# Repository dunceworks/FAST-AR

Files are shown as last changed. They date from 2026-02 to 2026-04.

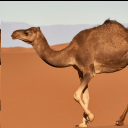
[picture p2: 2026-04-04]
py/test_img_gen/output_img/downscaler_param_128square.png

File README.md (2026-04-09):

# FAST-AR: Framework for Accelerated Spatial awareness in Augmented Reality

Designed to provide accelerated gesture recognition through hardware acceleration of image preprocessing combined with the Xilinx DPU to enable high speed recognition.
Additionally, a Rubik Pi provides video passthrough and "pseudo-stereo" display for the user, allowing for easier integration of the AUP-ZU3 provided gesture data compared to a PL only approach

Note that some work is not present in this repository to prevent bloat. For example PCAM5 video and DPU are in separate repositories or only pieces of them are stored here respectively.
The PCAM repository is separate from this one and can be found at https://github.com/Henrywwg/pcam5.

Uses RGB888 color version

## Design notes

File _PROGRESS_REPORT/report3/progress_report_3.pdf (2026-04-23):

ECE554 | 1
Progress Report
2026-04-23

Members
Henry Wysong
Harshul Jalan
Ananya Virmani
Andrew Cadiena

Current Progress
So far, we have many of the main parts of our MVP at least partially tested. The PS/Rubik Pi based video passthrough is functional. Additionally, the gesture recognition model is almost finalized, undergoing additional minor training to improve confidence. The PL side video input is also working with frames being able to be pushed into main memory. The PS side now also successfully can run our proprietary model. Additionally the frame preprocessing modules are working. A debug video output now also works over mDP. The gesture recognition model also now works on the AUP-ZU3 (at 3.33 spf).

To Do
The main tasks to still complete are with integration and ensuring communication from the AUP-ZU3 to the Rubik Pi.
The IR sensor must still be finalized in its hardware implementation although in testbenching it is working.

What’s been Tested
All of our IP/hardware modules are now successfully testbenched. Below are the modules that are testbenched but are not integrated into the main block diagram yet due to ongoing HW debugging or other integration delays.

Testbenched
The IR sensor interfacing hardware has been testbenched. Additionally all of the secondary/(some) reach modules (such as extra filters) have also been testbenched and are ready to be integrated into the hardware time permitting. Otherwise all other modules have been fully testbenched in modelsim/vivado and are in or past the hardware testing stage.

HW Tested
Below is a list of the IP and hardware components that have been tested and shown working. Proof of this can be found in previous presentations, on github or upon request.
- VDMA
- PCAM/Video input
- Downscaler
- Grayscale

Individual Contributions
Henry
I have worked on the PL video input for gesture recognition along with the downscaler, grayscale and VDMA. Additionally I also was responsible for getting the DPU block diagram working from the HW side. For the downscaler and grayscale, I made an AXI4-Stream interfaces and testbenched the modules. After testbenching, IP was packaged and the block diagram was made. Our final design is the one BD which has the video processing pipeline, which is my main contribution. Co-opted feeding live data from VDMA into the model. I have contributed to getting the model running (from the hardware perspective - not the software) by working on moving data from the PL side into PS. I also have a working demo display that shows the area that is being downscaled to guide users’ gesture/hand positioning.

Andrew
I have helped with VDMA and started the display port to output as one of our backup modules.
Currently I am working on integrating the IR sensor onto the board. The sensor outputs high if it detects an object within a set distance and I plan to then output audio in order to alert the user. The core verilog pipeline is completed, however configuring the AUP’s audio codec is proving a great challenge and I may pivot to another alternative. The current proposed backup is shifting to a PWM module and outputting through one of the boards GPIO pins. With a buzzer or a custom earbud wiring.

Ananya

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
3 I have m

ainly

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
ritin

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
nitio

n

m

o

d

el a

n

d

t

e

s

t

e

d it. Fin

al w

o

r

kin

g

s

o

n it are still in progress just to make sure that it works with the highest possible confidence level and fast. Alongside, I have been working on helping set up the DPU and getting the gesture recognition model to work on it. The DPU seems to be working independently but we are still running into software issues of loading the model on it. Lastly, I have been helping with some stuff on communication with the RubikPi and some integrations. Ananya also got MediaPipe installed and the gesture recognition model running on the AUP. Also co-opted working on feeding live data from VDMA into the model. Harshul I have worked on the PS/Rubik Pi based video passthrough, which is now functional and enables streaming frames into the AUP-ZU3 for further processing. Additionally, I have contributed to overall system integration, ensuring that different components in the pipeline (video capture, preprocessing, and inference) are aligned and can work together. I have also been involved in planning and structuring the communication between the AUP-ZU3 and Rubik Pi. This includes defining how gesture recognition outputs will be sent back for further processing and user interaction. This communication layer is currently still to be implemented as part of the remaining integration work.Additionally, I have the rover (for the headset to interact with and drive the rover using the hand gestures) system set up and ready to receive commands, and I will be working on establishing communication between the two Rubik Pis (on the rover and the VR headset) to enable end-to-end control.

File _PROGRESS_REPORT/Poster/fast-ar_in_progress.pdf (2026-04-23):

## Henry Wysong-Grass Ananya Virmani

## Harshul Jalan Andrew Cadiena

# ECE554 FAST-AR

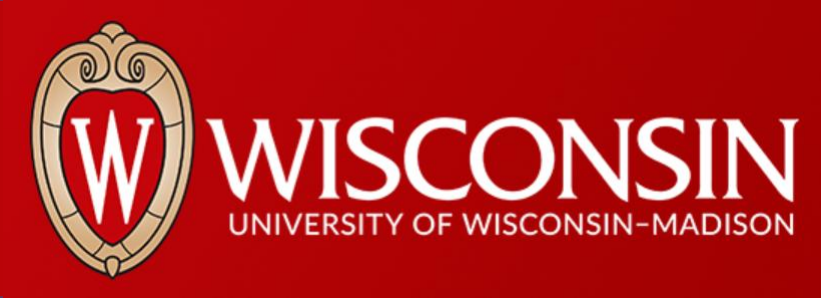
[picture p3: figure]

Overview | Software Pipeline (PS)

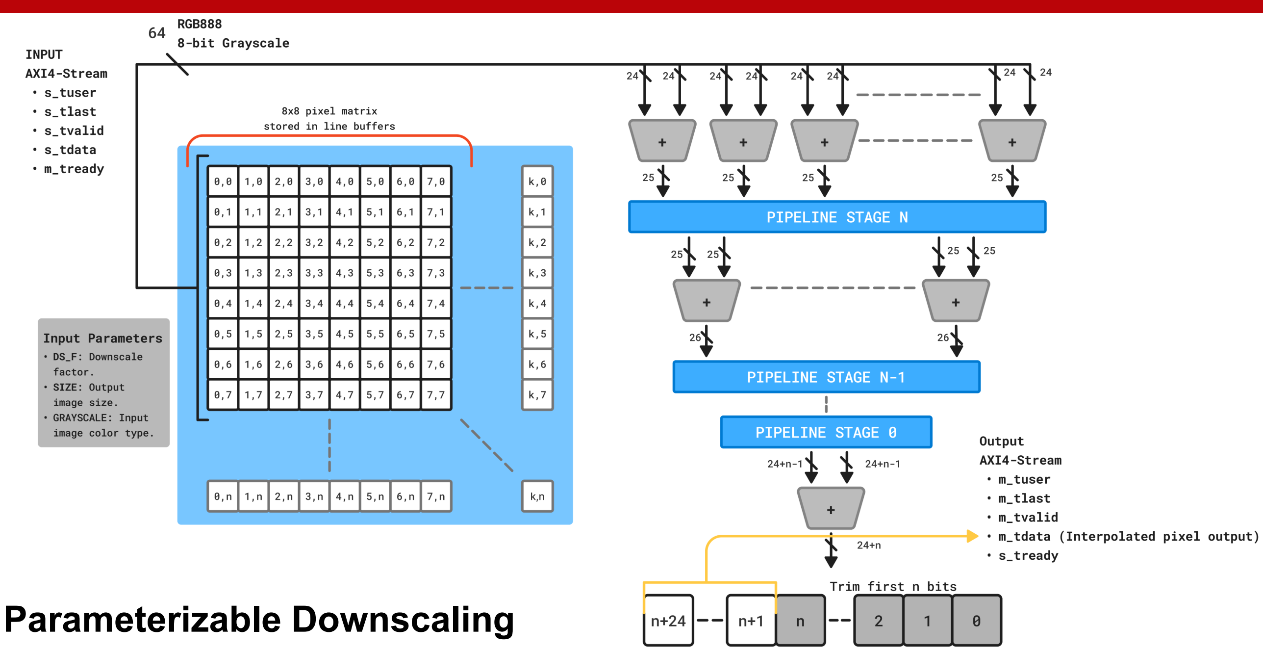
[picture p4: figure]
Parameterizable Downscaling

# Hardware Pipeline (PL)

# Gesture Acceleration Hardware

# Future Work

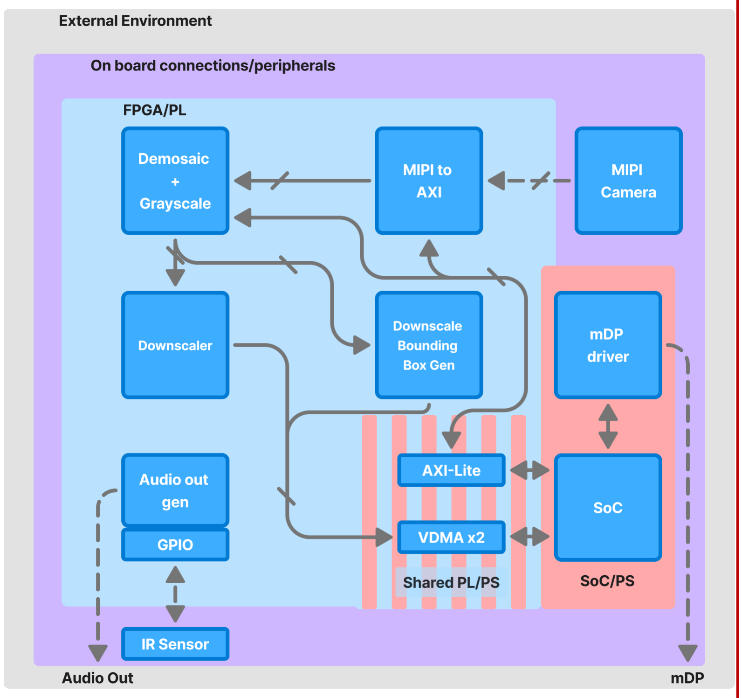
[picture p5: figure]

# Challenges

# Spring 2026

PYNQ Ecosystem
- MediaPipe for the model required internet, but the AUP lacks WiFi or ethernet.
- Long flash times and opacity of the FPGA lead to long software deployments.
- PYNQ’s Jupyter notebooks often disconnect mid program.
Custom IP
- Properly complying with the AXI4-Stream protocol is difficult!
- Cameras are prone to dropping pixels meaning all pipeline hardware must be robust and able to recover based on AXI4-Stream handshake signals. IP Configuration and Documentation
- Vivado/Xilinx IP configuration requires large time sink to both configure properly in hardware and then configure properly over an AXI-lite bus.
Hardware Failures and the AUP-ZU3…
- AUP-ZU3 boards have poor ESD protection and often fail short.
- PCAM5 modules are also sensitive and prone to ESD events.

Deep Processing Unit (DPU) accelerated Gesture Recognition
- DPU is a proprietary RISC core(s) on FPGA fabric that runs the recognition model.
- Zero software overhead but increases HW complexity and configuration complexity. High resolution (4K) global shutter camera
- Global shutter removes motion blur which gives higher quality images to the model.
- Higher resolution gives more data, allowing for better downscaled images. Hardware stereoscopic video pipeline (HW SBS)
- A HW video pipeline reduces software overhead immensely and reduces camera to display latency by an order of magnitude. Below are SWAGs of latency of each.
- HW SWAG → ~3000 cycles @ 200MHz ≈ 15 μS (as low as 100 nS for raw feed)
- SW SWAG → 2 DRAM R/W + SW processing ≈ 25 mS (conservative)
- Streams a 1080p frame and does NxN interpolation taking about 76.8 μS* per frame.
- Uses an auto-pipelining** adder tree to increase odds of meeting timing without designer intervention. No DSP slices are used due to tree design and bit manipulation!
- Operates on both RGB888 data or grayscale data depending on model type. Grayscale operation gives a 2/3 reduction in FPGA resources utilized.
Grayscale
- A module that converts a full color RGB image to a single, averaged channel (8 bit).
- Very useful for resource or compute constrained systems due to 2/3 reduction in data.

* 76.8 μS is the time to downscale one 1080p frame to 224x224 before it is sent to VDMA/Mapped Main Memory assuming operation at 200MHz with no stalls and does not account for blanking time of the frame.
** Automatic pipelining done at instantiation or synthesis.

Video in and Demosaic
- Camera data over 2-lane
CSI as RAW10.
- RAW10 data truncated to
RAW8 and demosaiced.
- Data streams out as
RGB888 over AXI4-Stream.

Primary Pipeline
- RGB data is downscaled
from 1080p to 224x224.
- Downscaled frame is pushed to Video Direct Memory
Access (VDMA).

Secondary/Demo Pipeline
- Split stream is grayscaled.
- A bounding box is drawn
over the downscaling region.
- Bound image sent to VDMA.

### FPGA Accelerated Spatial Tracking in Augmented Reality (FAST-AR)

Objective: Accelerate a gesture recognition model to decrease latency for augmented reality controls.

Architecture: Heterogenous System-on-Chip (SoC) co-design using both programmable logic (FPGA/PL) and a processing system (SoC/PS) for gesture acceleration, supported by an external SoC for video pipeline.

Hardware Contribution: Hardware frame preprocessor to reduce SoC/PS load by reducing problem size, handling all interfacing and downscaling.

Demo: Controlling a rover via hand gestures to demonstrate the effectiveness of a hardware accelerated gesture recognition model.
Additionally, we demonstrate what the hardware is doing by displaying image captured by the camera and the region of interest (ROI) that the downscaler operates on.

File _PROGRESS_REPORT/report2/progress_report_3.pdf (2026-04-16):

ECE554 | 1
Progress Report
2026-04-16

Members
Henry Wysong
Harshul Jalan
Ananya Virmani
Andrew Cadiena

Current Progress
So far, we have many of the main parts of our MVP at least partially tested. The PS/Rubik Pi based video passthrough is functional. Additionally, the gesture recognition model is almost finalized, undergoing additional minor training to improve confidence. The PL side video input is also working with frames being able to be pushed into main memory. The PS side now also successfully can run our proprietary model. Additionally the frame preprocessing modules are working. A debug video output now also works over mDP.

To Do
The main tasks to still complete are with integration and ensuring communication from the AUP-ZU3 to the Rubik Pi. The AUP-ZU3 PS gesture model must also be fully tested and integrated into the PL pipeline by ensuring frames are passed into it untorn.
As part of our minor reach goals is IMU integration in which progress has been halted. Focus is being shifted to implementing an IR sensor in order to alert the user if they are too close to an obstacle. The IR sensor must still be finalized in its hardware implementation although in testbenching it is working.

What’s been Tested
All of our IP/hardware modules are now successfully testbenched. Below are the modules that are testbenched but are not integrated into the main block diagram yet due to ongoing HW debugging or other integration delays.

Testbenched
The IR sensor interfacing hardware has been testbenched. Additionally all of the secondary/(some) reach modules (such as extra filters) have also been testbenched and are ready to be integrated into the hardware time permitting. Otherwise all other modules have been fully testbenched in modelsim/vivado and are in or past the hardware testing stage.

HW Tested
Below is a list of the IP and hardware components that have been tested and shown working. Proof of this can be found in previous presentations, on github or upon request.
- VDMA
- PCAM/Video input
- Downscaler
- Grayscale
- DPU**Not for use in internal demo any more. See below.

Individual Contributions
Henry
I have worked on the PL video input for gesture recognition along with the downscaler, grayscale and VDMA. Additionally I also was responsible for getting the DPU block diagram working from the HW side. For the downscaler and grayscale, I made an AXI4-Stream interfaces and testbenched the modules. After testbenching, IP was packaged and the block diagram was made. Our final design is the one BD which has the video processing pipeline, which is my main contribution. The DPU, which is now reach, is currently separated in its own diagram to make testing easier. We are now shifting to PS side gesture recognition for our internal demo with using the DPU as a public demo reach. I have also worked on other filters for the video input such as Sobel and crop+frame stitch. These are mostly working in HW barring some AXI4-Stream bugs.

Andrew
I have helped with VDMA and started the display port to output as one of our backup modules. Primarily I have worked on IMU integration to design the compass feature of our display. The compass ring sprite is designed and ready to test alongside other display modules. The compass needle is written and will be tested soon. Although as of writing we still have not received the IMU yet, I am going ahead on focusing efforts on the requested one in order to begin logging the

ECE554 | 2
Progress Report
2026-04-16

important registers we need to read from and how
to interface with it. This one should be SPI communication with the primary data needed buying rotation about the Z axis, but other data points can be looked at as well.
While IMU progress is halted, I am instead working on integrating the IR sensor to the design. The sensor outputs high if it detects an object within a set distance and I plan to then output audio in order to alert the user.

Ananya
I have mainly worked on writing the gesture recognition model and tested it. Final workings on it are still in progress just to make sure that it works with the highest possible confidence level and fast. Alongside, I have been working on helping set up the DPU and getting the gesture recognition model to work on it. The DPU seems to be working independently but we are still running into software issues of loading the model on it. Lastly, I have been helping with some stuff on communication with the RubikPi and some integrations.

Harshul
I have worked on the PS/Rubik Pi based video passthrough, which is now functional and enables streaming frames into the AUP-ZU3 for further processing. Additionally, I have contributed to overall system integration, ensuring that different components in the pipeline (video capture, preprocessing, and inference) are aligned and can work together.
I have also been involved in planning and structuring the communication between the AUP-ZU3 and Rubik Pi. This includes defining how gesture recognition outputs will be sent back for further processing and user interaction. This communication layer is currently still to be implemented as part of the remaining integration work.
Additionally, I have the rover (for the headset to interact with and drive the rover using the hand gestures) system set up and ready to receive commands, and I will be working on establishing communication between the two Rubik Pis (on the rover and the VR headset) to enable end-to-end control.

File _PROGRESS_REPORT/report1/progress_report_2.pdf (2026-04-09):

ECE554 | 1
Progress Report
2026-04-09

Members
Henry Wysong
Harshul Jalan
Ananya Virmani
Andrew Cadiena

Current Progress
So far, we have many of the main parts of our MVP at least partially tested. The PS/Rubik Pi based video passthrough is functional. Additionally, the gesture recognition model is almost finalized, undergoing additional minor training to improve confidence. The PL side video input is also working with frames being able to be pushed into main memory. Additionally the frame preprocessing modules are working.

To Do
The main tasks to still complete are with integration and with loading the DPU with our proprietary model. Mainly, the DPU must be integrated into the larger block design, and then tested with model, or alternatively, use our current model and use the PS side of the AUP-ZU3 to do the gesture recognition. After the AUP-ZU3 internal integration, we must have the PS side of the AUP send gesture recognition data to the Rubik Pi for processing.
As part of our minor reach goals is IMU integration in which progress has been halted. Focus is being shifted to implementing an IR sensor in order to alert the user if they are too close to an obstacle.

What’s been Tested
Our project has several IPs at different stages of completion. IP that has not yet been tested but has been testbenched is shown accordingly. If IP has been shown to work in hardware it will appear only under HW tested with the implication that it has also been testbenched.

Testbenched
The compass ring sprite has been testbenched and needle rotation module testbenching is in progress. Additionally all of the secondary/reach modules (such as extra filters) have also been testbenched and are ready to be integrated into the hardware time permitting. Otherwise all other modules have been fully testbenched in modelsim/vivado and are in or past the hardware testing stage.

HW Tested
Below is a list of the IP and hardware components that have been tested and shown working. Proof of this can be found in previous presentations, on github or upon request.
- VDMA
- PCAM/Video input
- Downscaler
- Grayscale
- DPU*

* The DPU can properly synthesize and appears to be in a ready state based on register values, but we have run into software issues with loading our detection model and are working to resolve these
Individual Contributions
Henry
I have worked on the PL video input for gesture recognition along with the downscaler, grayscale and VDMA. Additionally I also was responsible for getting the DPU block diagram working from the HW side. This mostly involved, for the downscaler and grayscale, creating AXI4-Stream interfaces and testbenching the modules. After testbenching in modelsim, I packaged the IP and designed the block diagrams. This boils down to mainly one block diagram now which takes in video from the PCAM, does preprocessing and then offloads it to main memory.
For the DPU, it is currently separated in its own diagram to make testing easier. I have gotten it to work by poking at it using MMIO registers, but we don’t have it functionally working with our model (problem described above). I have also worked on other filters for the video input should we decide to use them later. These are not part of the MVP but have been test benched in the same way as the other modules have been.

ECE554 | 2
Progress Report
2026-04-09
Andrew
I have helped with VDMA and started the display port to output as one of our backup modules. Primarily I have worked on IMU integration to design the compass feature of our display. The compass ring sprite is designed and ready to test alongside other display modules. The compass needle is written and will be tested soon. Although as of writing we still have not received the IMU yet, I am going ahead on focusing efforts on the requested one in order to begin logging the important registers we need to read from and how to interface with it. This one should be SPI communication with the primary data needed buying rotation about the Z axis, but other data points can be looked at as well.
While IMU progress is halted, I am instead working on integrating the IR sensor to the design. The sensor outputs high if it detects an object within a set distance and I plan to then output audio in order to alert the user.

Ananya
I have mainly worked on writing the gesture recognition model and tested it. Final workings on it are still in progress just to make sure that it works with the highest possible confidence level and fast. Alongside, I have been working on helping set up the DPU and getting the gesture recognition model to work on it. The DPU seems to be working independently but we are still running into software issues of loading the model on it. Lastly, I have been helping with some stuff on communication with the RubikPi and some integrations.

Harshul

I have worked on the PS/Rubik Pi based video passthrough, which is now functional and enables streaming frames into the AUP-ZU3 for further processing. Additionally, I have contributed to overall system integration, ensuring that different components in the pipeline (video capture, preprocessing, and inference) are aligned and can work together.

I have also been involved in planning and structuring the communication between the AUP-ZU3 and Rubik Pi. This includes defining how gesture recognition outputs will be sent back for further processing and user interaction. This communication layer is currently still to be implemented as part of the remaining integration work.

Additionally, I have the rover (for the headset to interact with and drive the rover using the hand gestures) system set up and ready to receive commands, and I will be working on establishing communication between the two Rubik Pis (on the rover and the VR headset) to enable end-to-end control.

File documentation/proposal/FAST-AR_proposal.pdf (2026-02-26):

ECE 554: FAST-AR Proposal | 1
2026-02-25
Framework for Accelerated SpaTial awareness in Augmented Reality (FAST-AR)
I. Project Overview
1. Idea and Application
The objective of this project is to design and
develop a hardware accelerated assistive learning augmented reality (AR) headset for use in training or fast navigation settings. FAST-AR aims to implement a direct FPGA video processing pipeline using an AUP-ZU3 FPGA/SoC. By providing microsecond latencies, and visual filters, users will enjoy improved navigational awareness in a seamless experience while eliminating motion sickness associated with software based AR/HUDs [1].
2. Motivation
In technical environments, or during fast navigation, even small amounts of delay in an AR/HUD display can result in motion sickness [1]. Our project aims to eliminate this by providing near-zero latency video processing, enhancing user experience.
II. Technical Approach
1. Methodology/Architecture
Our architecture implements a heterogeneous architecture using the ZU3 MPSoC. Video data obtained from the on-board MIPI connector will be streamed directly to the FPGA programmable logic (PL). In our PL, One pipeline will then process low-latency, high-fidelity video, while another serves as a graphics overlay pipeline. Finally, the processed video is streamed out through the mini-DisplayPort (mDP). Meanwhile, the SoC will simultaneously collect navigation data and relay coordinates via AXI-lite to the FPGA to aid in placing “virtual” aid objects with minimal CPU/SoC overhead, reducing power draw of the SoC [2].

Low Latency Video Architecture: Video capture is managed by the FPGA over the MIPI interface. The video will then be processed in several
different | parallel | pipelines | to | undergo
demosaicing, contrast adjustments, sharpening and edge-detect. A final stage will be at the end of the pipeline. Here simple UI elements are overlaid based on data provided from the SoC (described below) and finally, to compensate for the biconvex lenses found in AR style headsets, barrel distortion may be added via a live distortion algorithm [3].

Graphics & Filtering: The system will also inject navigation data directly into the video stream using a dedicated Hardware Sprite Engine. The ARM SoC receives direction strings (e.g., directional arrows or distance markers) from a smartphone and writes these coordinates to set registers on the FPGA. These registers will be written over the AXI protocol. After reading these values, the Sprite Engine reads these shapes from on-chip BRAM and overlays them onto the live video feed. A module will then mix these graphics with the live frame, allowing directions to appear as if they are floating in the physical environment. This approach replaces complex software-based UI rendering with high-speed hardware logic, significantly reducing SoC utilization.

2. Justification
This project is well suited for 554 due to its heavy reliance on FPGA processing, along with the use of a heterogeneous system. This provides complexity through system interfaces such as SoC to FPGA and the need to perform low latency processing of high fidelity video frames at a high framerate. Additionally, for some UI/overlay elements, head motion will need to be monitored so some sensors such as an IMU will be needed. These sensors will require additional SPI, UART or I2C interfaces to be implemented and monitored. Our design is novel in that the graphics are entirely managed by the FPGA with data being supplied from the SoC. This allows for very low latency and smooth operation that will improve user experience.
Additionally, FPGAs are designed exactly for such high-speed, low-latency processing and so prevents the end user from suffering nausea due to high latency and low framerate. Many filters that we will use are memory-bound on an SoC, such as kernel operations for filtering and potentially barrel distortion. Without the FPGA PL, this project would be entirely ineffective at its intended goal of improving user awareness.
III. Strategy
1. Anticipated Challenges
We anticipate several challenges with implementation. Chief among these we anticipate interfacing with the MIPI camera(s), and creating a video pipeline capable of handling high framerate full RGB video at near zero latency to be challenging. Depending on the exact filters implemented, up to several MB of BRAM may be needed to realize our image processing, so managing memory at these bounds will be challenging.
Additionally, we expect challenges with buffering large amounts of high speed, high fidelity data. Depending on the end resolution of our camera, up to several MB of data may be needed for image processing techniques and filters. Further, implementing live barrel distortion is a documented process, but translating the complex mathematics and memory mapping into efficient, real-time Verilog logic will be a significant developmental hurdle and so is left as a reach goal [3].
2. Risk Mitigation
To mitigate risk, we first will focus on physical risk including risk to the board, for this, Henry will manufacture a polycarbonate shell for the FPGA to provide physical and ESD protection. If we encounter issues with the SoC to FPGA communication, we will shift to an all-FPGA focused approach where sensors on the headset will provide basic cardinal directions. The largest concern we have is that our Xilinx board will fail. In the event, our new MVP will shift to using the DE1-SoC. In this scenario we will follow a similar path as if the SoC→FPGA communication is unfeasible and focus only on filtered video throughput with sensor assisted directionality. IV. Timeline & Evaluation Method
To evaluate our progress throughout the semester, we will employ two main milestones to keep the project on track
Mid-Term Criteria: Successful implementation of the MIPI→mDP video passthrough pipeline. The FPGA must be able to read a frame from the MIPI camera, perform basic image preparation (demosaicing), apply basic hardware filters (e.g., grayscale or edge detection), and output it to the mDP without visual tearing. Additionally, the SoC will be able to pass basic values to the FPGA via AXI .
Final Criteria (MVP): Full integration of the heterogeneous architecture. The FPGA will dynamically draw the overlay and filters at a minimum of 30 frames per second to ensure a tolerable AR experience and perform the requisite filtering and low latency. The SoC will provide navigational data to the FPGA which will then be rendered as part of the overlay.

Below is a rough timeline for our project detailing both PL and PS goals. Gantt will be used for actual progress tracking. For access email Henry.

Week | PL | PS
1-2 | MIPI→FPGA→ mDP; begin sprite engine | OS setup; investigate setup for online data receipt
2-4 | AXI→FPGA register writing; test sprite drawing | Memory mapped I/O setup; send dummy data to FPGA registers
4-6 | Finalize image filtering; begin work on image integration and overlay. | Integrate Bluetooth/UART stack; parse incoming navigation strings.
6-8 | Finish image overlay; ensure timing for 30fps; Barrel distortion | Finalize PYNQ-based UI driver; optimize register write
V. Members and Responsibilities
Harshul Jalan brings experience in HW/SW codesign, system architecture and embedded systems. Further background includes RTL development, AXI interfacing and MM I/O. He will define system architecture and PS/PL integration including video pipelining, overlay, filtering, UI, Bluetooth/UART stack and AXI register writing. Andrew John Cadiena brings a skillset in digital system design and embedded and parallel systems. His interests lie in RTL module development as well as computer architecture. He will be responsible for implementing sprite overlay on the display.
Ananya Virmani brings with her a mixed experience of hardware and software focussing on digital design, computer architecture. Her interests lie in RTL development, OS, C programming and testbenching. She will be responsible for testbenching modules, overlay onto live images, assist with the software stack and UART stack. Henry Wysong-Grass has experience in digital system design, especially in RTL development, C firmware, and testbenching. Their interests lie in low-energy computing. They will be responsible for the core video pipeline (MIPI to FPGA to mDP), filters, IMU integration and testbenching modules.

Several tasks will “float” throughout the semester such as MIPI configuration (camera dependent) creating sprites and barrel distortion.

### References

[1] F. M. Alessa, M. H. Alhaag, I. M. Al-Harkan, M. Z. Ramadan, and F. M. Alqahtani, “A Neurophysiological Evaluation of Cognitive Load during Augmented Reality Interactions in Various Industrial Maintenance and Assembly Tasks.,” Sensors (Basel), vol. 23, no. 18, Sep. 2023, doi: 10.3390/s23187698.
[2] Real Digital, “AUP-ZU3 Reference Manual.” 2025. [Online]. Available: https://www.realdigital.org/downloads/3cd0cbae4d00eaf94270e5792c746d4c.pdf
[3] H. Blasinski, Wei Hai, and F. Lohier, “FPGA architecture for real-time barrel distortion correction of colour images,” in 2011 IEEE International Conference on Multimedia and Expo, Jul. 2011, pp. 1–6. doi: 10.1109/ICME.2011.6011854.

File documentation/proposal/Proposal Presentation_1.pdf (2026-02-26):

# FAST-AR Proposal

Ananya Virmani, Harshul Jalan, Henry Wysong-Grass,

## Andrew John Cadiena

## Problem Statement

What is the specific challenge you are solving?

- Software-based AR causes motion sickness due to high latency and burns through battery life

Why is an FPGA better for this than a standard CPU or microcontroller? (Think

concurrency, latency, or custom IO)

- We need microsecond latencies and massive concurrency that standard CPUs simply can't provide.
- GEMM operations are often memory bound - live FPGA processing eliminates this.

## Proposed Solution & Features

High-level overview of your system.

Key Features: List 3–4 "Must-haves" and 1–2 "Stretch goals" (features you'll add if

you finish early).

Must-haves:

- Direct MIPI-to-mDP video passthrough
- Real-time hardware filters (Edge-detect, Sharpening)
- Hardware Sprite Engine for navigation overlays

Stretch Goals:

- Live Barrel Distortion algorithm to fix biconvex lens warping

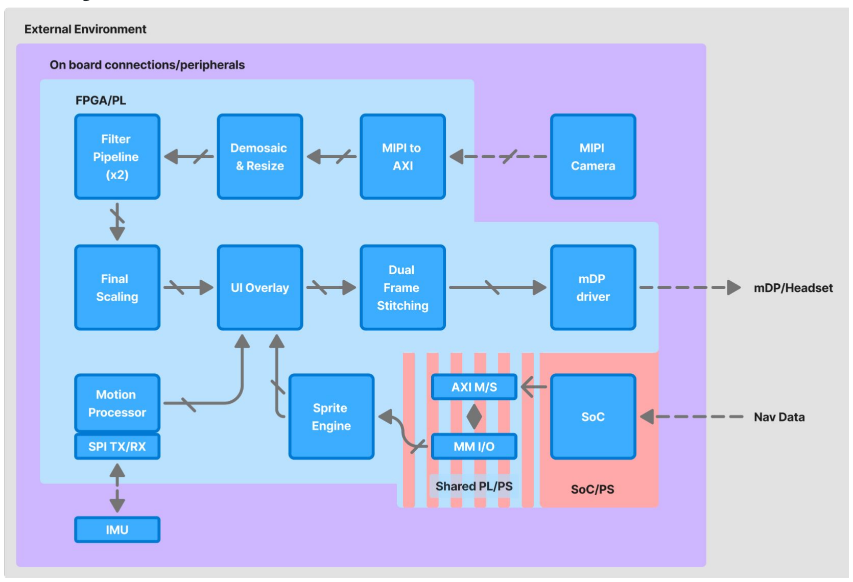
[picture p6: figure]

FPGA/PL handles…
- Core video pipeline
- IMU interface + processing
- Sprite rendering
- UI/Sprite overlay

SoC/PS handles…
- Bluetooth interfacing
- Collecting nav data

Shared PS/PL…
- MM I/O: SoC 🡘 FPGA via AXI

## System Architecture

## Detailed Hardware Modules

Break down your custom RTL modules at a high-level.

- Mention specific protocols you'll use: I2C, SPI, UART, or high-speed interfaces like

HDMI/VGA.

## Resource Estimate

I/O Devices: MIPI Camera, mini-DisplayPort, and IMU sensors.

Memory: Several MB of on-chip BRAM needed for image buffering and sprite storage.

Timing: 30 FPS minimum target to ensure a tolerable AR experience (hopefully)

## Verification Plan

- RTL Unit Testing (Simulation) using QuestaSim for all key modules
- SignalTap or ILA (Integrated Logic Analyzer) allow for probing internal signals while the board is running.
- I/O Verification: Ensuring the UART stack correctly parses incoming navigation strings and updates the hardware sprites accordingly
- Final Demo Verification - Ensuring that the final headset works as expected without any issues and if yes, debugging those.

## Project Timeline

## Potential Challenges & Risks

- The initial challenge for us would be to make use of the Xilinx board because we have no prior experience with it and the camera module do

## Conclusion and Expected Outcome

What does the final demo look like? (e.g., "A live video feed with a 60fps filter applied

via hardware").

- Expected takeaway from this project.

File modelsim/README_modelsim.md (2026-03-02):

2026-03-02
Henry Wysong

This folder is empty as each member should initialize their own local project. do NOT upload files into this folder as they will be deleted.
If you do not modify the .gitignore file, then you should be able to make a project in this directory with no problem and push/pull.

Remember we are using the Xilinx board as well. I am using modelsim for fast simulation checking of modules since I'm more comfortable with it.

Leave this .md alone.

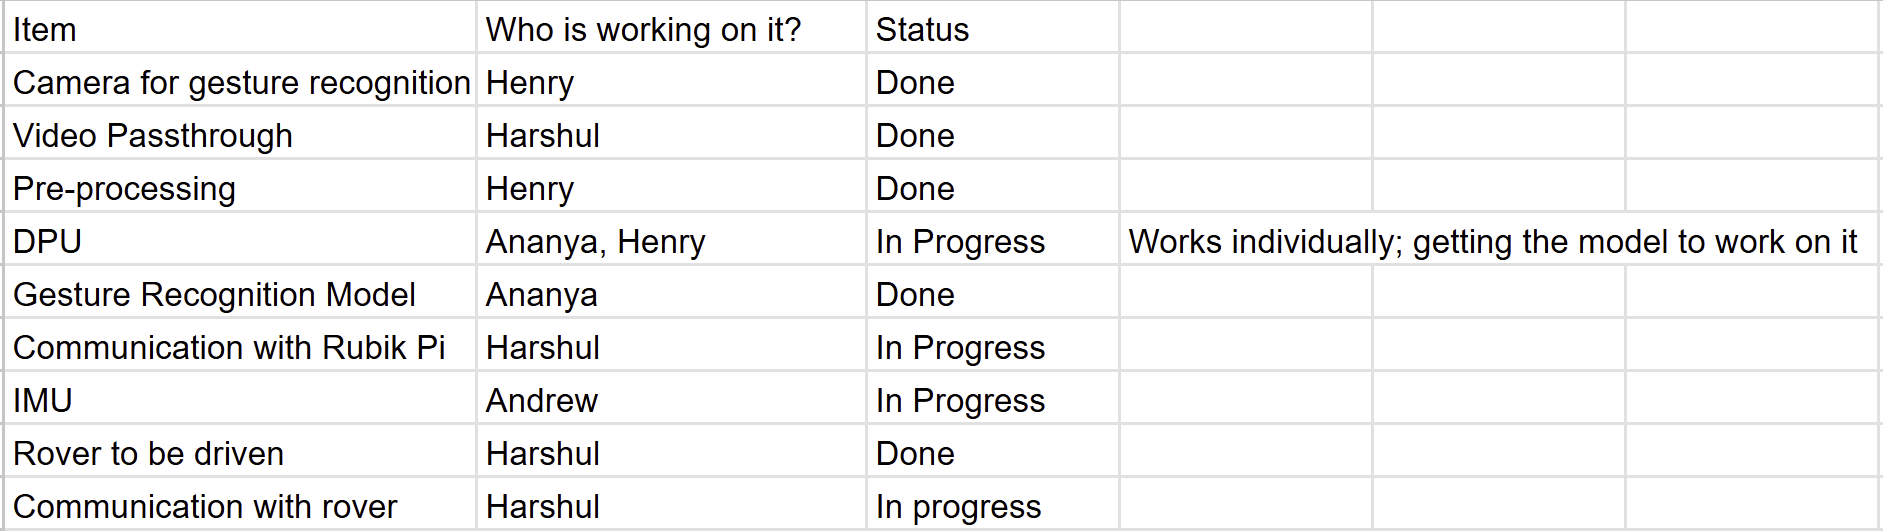
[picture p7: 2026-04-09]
_PROGRESS_REPORT/report1/progress_sheet.png

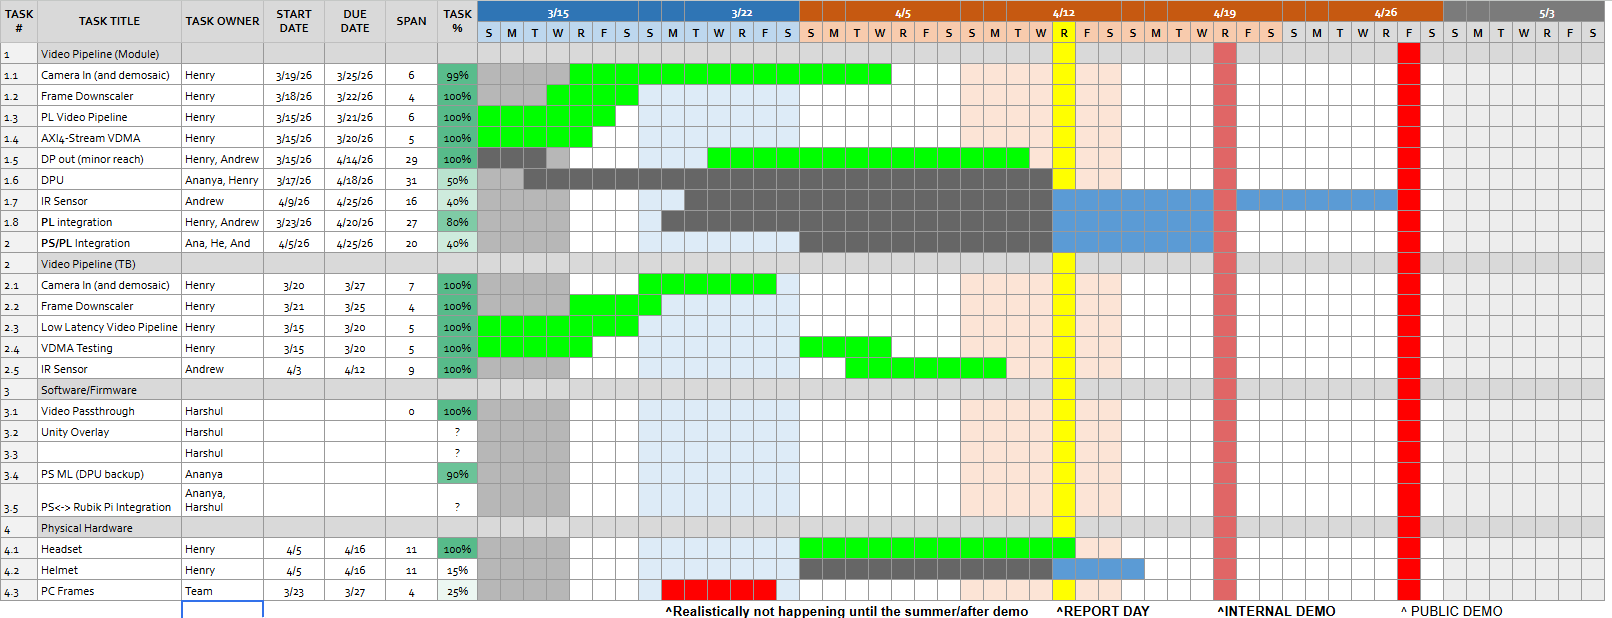
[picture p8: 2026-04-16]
_PROGRESS_REPORT/report2/report2.png

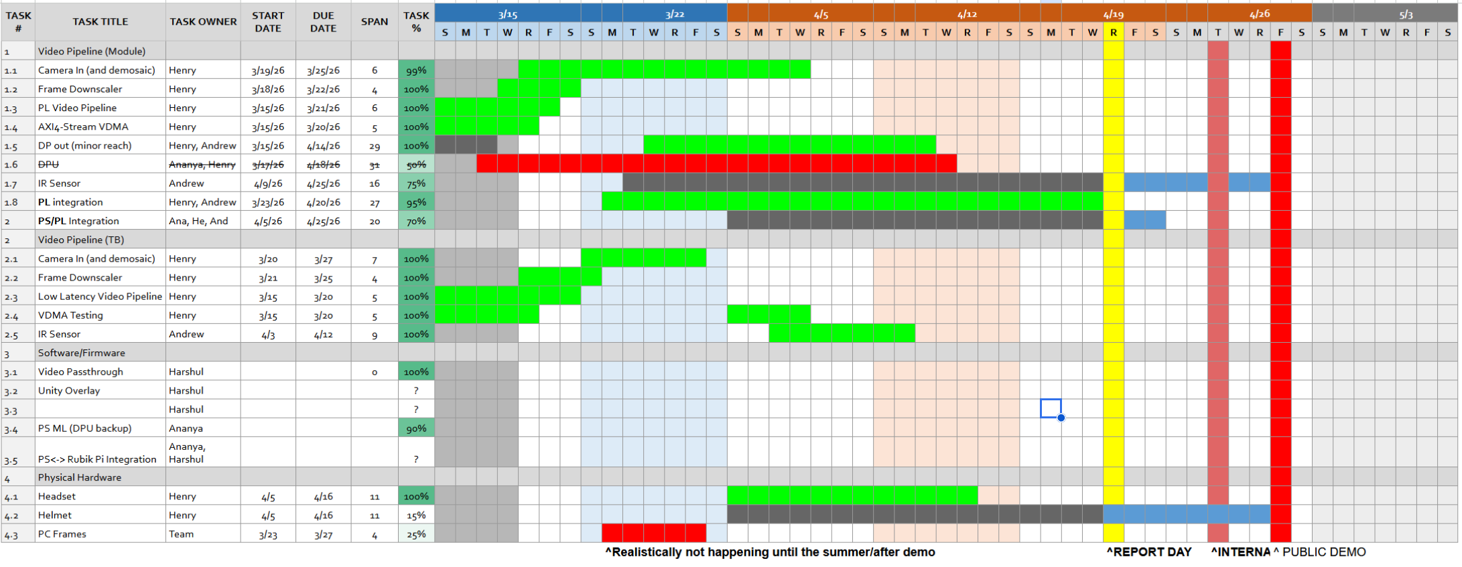
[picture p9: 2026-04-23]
_PROGRESS_REPORT/report3/timeline3.png

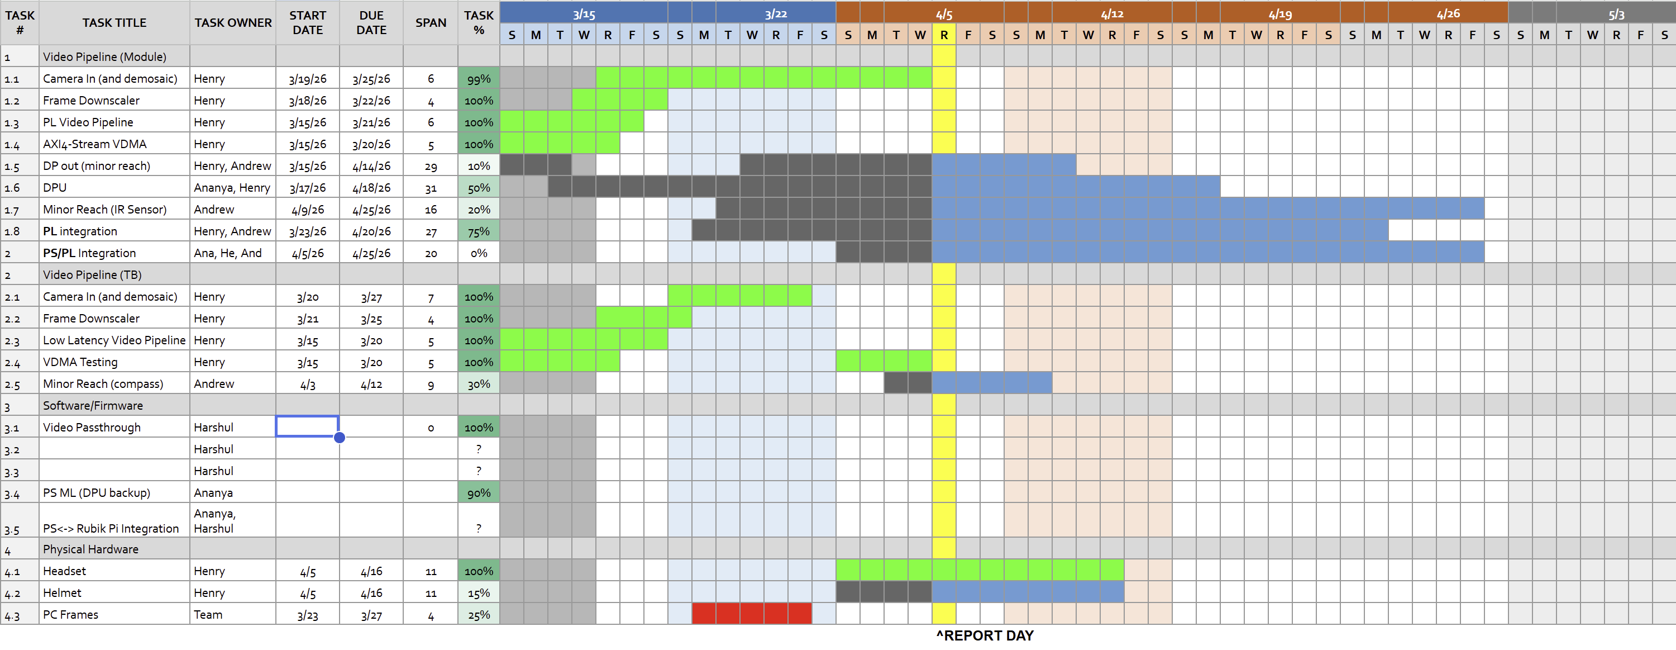
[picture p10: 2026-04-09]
_PROGRESS_REPORT/report1/progress_image_chart.png

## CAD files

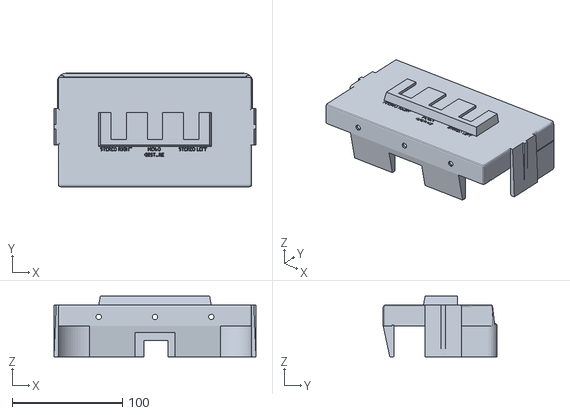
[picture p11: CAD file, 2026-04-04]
mechanical_engineering_thing_I_guess/headset_mount_ECE554_FASTAR.stl
183.0 x 103.0 x 55.0

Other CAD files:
mechanical_engineering_thing_I_guess/headset_mount.ipt

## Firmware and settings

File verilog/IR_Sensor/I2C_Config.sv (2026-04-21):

////////////////////////////////////////////////////////////////// 
//
// File name: I2C_Config.sv
// 
// Description: Module to configure the audio codec
//
// Created  : 2026-04-09
// Modified : 2026-04-21
// Author(s): Cadiena
//
// Team     : Dunce Works
//
// Written?     []
// Tested?      []
//
///////////////////////////////////////////////////////////////////

`default_nettype none

module I2C_Config (
    input  wire clk,         // Your 100MHz PL clock
    input  wire rst_n,       // Active-low reset
    
    // Codec I2C Pins
    inout  wire I2C_SDA, 
    output wire I2C_SCL, 
    output reg  AIC_nRST,    // Codec reset pin (E2)
    
    output reg  config_done  // Goes high when finished
);

    // TLV320 I2C Address (7-bit) + Write bit (0) = 8 bits total
    localparam CODEC_WRITE_ADDR = 8'b0011000_0; 

    // --- 1. CLOCK DIVIDER ---
    // I2C is slow (100 kHz). We divide our 100MHz clock by 1000.
    reg [9:0] clk_div;
    reg i2c_en; // Pulses at 100kHz
    
    always @(posedge clk) begin
        if (clk_div == 999) begin
            clk_div <= 0;
            i2c_en <= 1;
        end else begin
            clk_div <= clk_div + 1;
            i2c_en <= 0;
        end
    end

    // --- 2. CONFIGURATION ROM ---
    localparam NUM_CMDS = 21;
    reg [15:0] rom [0:NUM_CMDS-1];
    
    initial begin
        // --- 1. INITIALIZATION & CLOCKS ---
        rom[0]  = 16'h0000; // Select Page 0
        rom[1]  = 16'h01_01; // Software Reset (Wakes up the chip)
        
        // Assume FPGA provides MCLK. Route MCLK directly to the Codec Clock.
        rom[2]  = 16'h04_00; // Clock Setting: PLL Off, Codec_Clk = MCLK
        rom[3]  = 16'h1B_00; // Audio Interface: I2S mode, 16-bit data, Codec is Slave

        // --- 2. DIGITAL PROCESSING SETUP ---
        rom[4]  = 16'h0B_81; // Power up NDAC divider (Value = 1)
        rom[5]  = 16'h0C_82; // Power up MDAC divider (Value = 2)
        rom[6]  = 16'h0D_00; // DOSR (Oversampling) MSB = 0
        rom[7]  = 16'h0E_80; // DOSR LSB = 128
        rom[8]  = 16'h3C_08; // Select standard DAC Signal Processing Block (PRB_P8)

        // --- 3. ANALOG & POWER SETUP ---
        rom[9]  = 16'h00_01; // Select Page 1 (Analog registers)
        rom[10] = 16'h01_08; // Disable internal crude AVdd (AUP-ZU3 provides clean 3.3V)
        rom[11] = 16'h02_01; // Enable Master Analog Power Control
        rom[12] = 16'h7B_01; // Set reference charging time to 40ms

        // --- 4. LINE OUT (LOL / LOR) ROUTING ---
        // Instead of routing to Headphones, we route to the AUP-ZU3's green audio jack
        rom[13] = 16'h0E_08; // Route Left DAC output to LOL
        rom[14] = 16'h0F_08; // Route Right DAC output to LOR
        rom[15] = 16'h12_00; // Unmute LOL, set gain to 0dB
        rom[16] = 16'h13_00; // Unmute LOR, set gain to 0dB
        rom[17] = 16'h09_0C; // Power up the LOL and LOR amplifiers (Bits 3 and 2)

        // --- 5. TURN ON THE AUDIO ---
        rom[18] = 16'h00_00; // Select Page 0 again
        rom[19] = 16'h3F_D6; // Power up Left & Right DACs, route I2S Left/Right channels respectively
        rom[20] = 16'h40_00; // Unmute the DAC Digital Volume Control
    end

    // --- 3. STATE MACHINE ---
    reg [4:0] state;
    reg [7:0] cmd_index;   // Which ROM command we are on
    reg [4:0] bit_count;   // Counting 8 bits for data shifting
    reg [7:0] shift_reg;   // Holds the current byte being shifted out
    
    // Open-Drain driving for SDA (Never drive 1, only pull 0 or float Z)
    reg sda_out;
    assign I2C_SDA = (sda_out == 0) ? 1'b0 : 1'bz;
    
    // Simple SCL driving
    reg scl_out;
    assign I2C_SCL = scl_out;

    localparam S_RESET = 0, S_START = 1, S_SEND_DEV_ADDR = 2, S_ACK1 = 3;
    localparam S_SEND_REG_ADDR = 4, S_ACK2 = 5, S_SEND_DATA = 6, S_ACK3 = 7;
    localparam S_STOP = 8, S_DONE = 9;
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

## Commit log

2026-03-04 Python filtering tests
2026-03-10 Image pipeline working (input 1080p --> crop + filter + composite --> frame stich)
2026-03-27 STL files for headset adapter (did this in 3 hours TwT)
    [headset_mount.ipt, headset_mount_ECE554_FASTAR.stl]
2026-04-14 Initial implementation of IR sensor integrating files
2026-04-14 IR sensor related python script, output, and codec clock generator
2026-04-16 IR Sensor Verilog modules testbenched
2026-04-16 fixed current compile errors
    [I2C_Config.sv]
2026-04-21 added demo material and hwh and bit files for easier debugging for team
